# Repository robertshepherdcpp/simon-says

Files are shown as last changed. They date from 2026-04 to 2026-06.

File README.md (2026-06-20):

# simon-says
my fourth project for fallout

**what is this project**
- test out your memory with this memory game!
- this project tests your sequence memory, in having a sequence that increases in length after everytime you get it right
- see how far you can go! how many can you remember in a row

**assembly instructions**
- print out the pcb and the case, and purchase the components meantioned in the bom
- put the pcb in the case
- put on the lid. then attach the screws mentioned in the BOM to fix the pcb in place.
- flash the firmware to the xiao-esp32 through the arduino ide (via usb)
- keep it plugged into your computer, as that will be the power source!
- try and see how many you can remember!

**inspiration for the project**
- having played the sequence memory game on [human benchark](humanbenchmark.com), i wanted to have a physical version of this that i could play with!
- i thought it would be a good way to try and improve my memory as having it in physical form i think makes me more likely to use it.

**how it works**
- the project will show the seqence of keys 1 by 1, you simply copy these!
- see how many of these you can remember!
- if you have a high score, the project  will flash 3 times (this high score is stored on the permanent storage of esp-32 board. (using preferences.h)
- if you press the wrong key, then all leds will flash once, and the sequence will reset, (back to a seqeunce of length 1, then you have to memorize a new sequence)
- keep trying to beat the PB!

**how this project was made**
- case made using fusion360
- pcb made using kicad
- in the 3d model, the keycaps and cherry-switches were imported as step files from repos on github.

**screenshots**
the schematic:



the footprint:



pcb 3d:



the 3d model:



zine:



bom:



total project cost: $28.53 (however will already have components spare from other projects like cherry mx switches, key caps)

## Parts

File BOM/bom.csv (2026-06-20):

Name | Description | Price | Link | Running Total
XIAO-ESP32-C6 | the mcu | $9.34 | https://www.aliexpress.com/item/1005007427033011.html?af=137191_1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 | $9.34
Cherry MX switches | the keys | $5.09 | https://www.aliexpress.com/item/1005012067128405.html?af=137191_1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 | $14.43
Key caps | caps | $2.36 | https://www.aliexpress.com/item/1005005513800132.html?af=137191_1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 | $16.79
LEDs | smt 0603 | $1.69 | https://www.aliexpress.com/item/1005011897792884.html?af=137191_1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 | $18.48
Resistors | smt | $0.95 | https://www.aliexpress.com/item/1005008650089395.html?af=137191_1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 | $19.43
PCB | pcb fabrication | $4.00 | www.jlcpcb.com | $23.43
PCB shipping | shipping pcb | $3.30 | www.jlcpcb.com | $26.73
Case | - | N/A | N/A | N/A
MCP23017 | gpio expander | $1.80 | https://www.lcsc.com/product-detail/C506653.html | $28.53

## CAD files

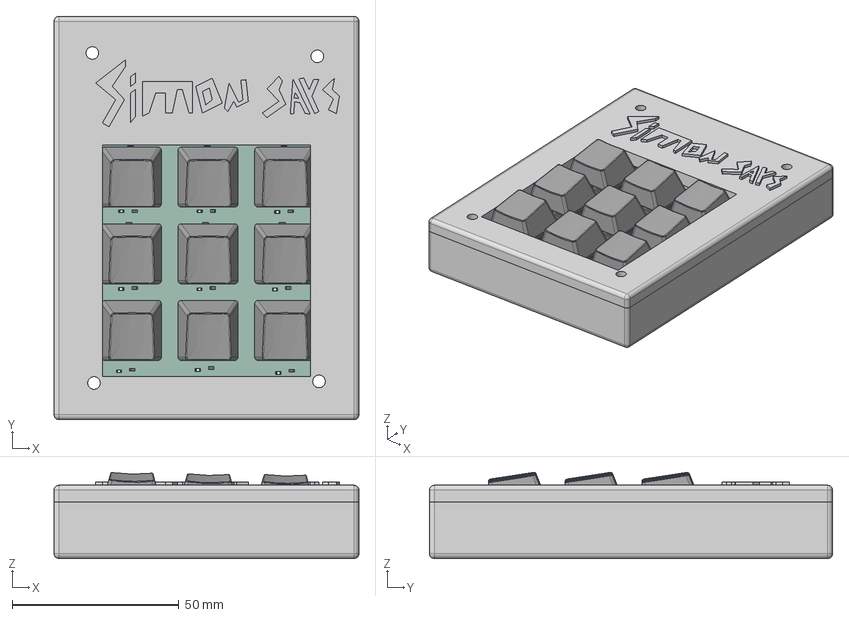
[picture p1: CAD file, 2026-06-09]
CAD/mg.step
91.5 x 121.0 x 25.8 mm
1x1 R1 v23 x 9
1x1 R2 v8 x 9
1x1 R3 v8 x 9
1x1 R4 v6 x 9
1x1.5 R1 v4 x 9
1x1.5 R3 v6 x 9
1x1.5 R4 v5 x 9
1x1.5 R2 v5 x 9
1x1.25 R1 v7 x 9
1x1.25 R2 v4 x 9
1x1.25 R4 v6 x 9
1x1.25 R3 v5 x 9
1x1.75 R1 v6 x 9
1x1.75 R2 v4 x 9
1x1.75 R4 v4 x 9
1x1.75 R3 v5 x 9
1x2 R1 v6 x 9
1x2 R4 v6 x 9
1x2 R3 v6 x 9
1x2 R2 v6 x 9
1x2.25 R1 v6 x 9
1x2.25 R2 v6 x 9
1x2.25 R4 v6 x 9
1x2.25 R3 v6 x 9
1x2.5 R1 v5 x 9
1x2.5 R2 v7 x 9
1x2.5 R3 v6 x 9
1x2.5 R4 v5 x 9
1x2.75 R1 v3 x 9
1x6.25 R1 v6 x 9
1x2.75 R4 v3 x 9
1x2.75 R3 v3 x 9
1x2.75 R2 v4 x 9
LED_0603_1608Metric x 9
R_0603_1608Metric x 9
QFN-28-1EP_6x6mm_P0.65mm_EP4.25x4.25mm
mg_PCB
BOSS-EXTRUDE14_8_
BOSS-EXTRUDE7_4_
BOSS-EXTRUDE7_3_
BOSS-EXTRUDE14_4_
BOSS-EXTRUDE14_2_
BOSS-EXTRUDE14_11_
BOSS-EXTRUDE7_7_
BOSS-EXTRUDE14_9_
BOSS-EXTRUDE14_3_
BOSS-EXTRUDE14_7_
MIRROR2
BOSS-EXTRUDE14_5_
BOSS-EXTRUDE14_12_
BOSS-EXTRUDE7_8_
BOSS-EXTRUDE7_1_
BOSS-EXTRUDE14_10_
BOSS-EXTRUDE7_9_
BOSS-EXTRUDE14_6_
BOSS-EXTRUDE14_1_
BOSS-EXTRUDE7_6_
BOSS-EXTRUDE7_2_
CUT-EXTRUDE5
BOSS-EXTRUDE7_5_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

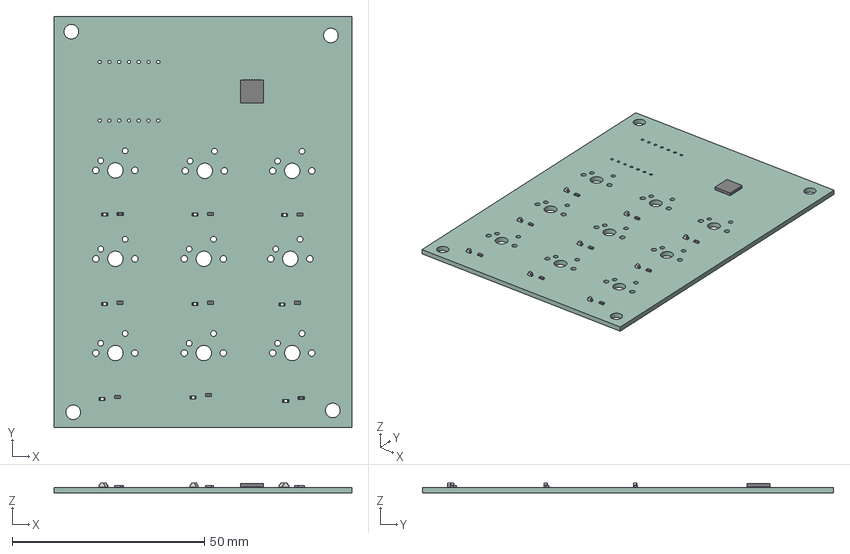
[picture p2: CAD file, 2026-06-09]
PCB/mg.step
77.5 x 107.0 x 2.70 mm
LED_0603_1608Metric x 9
R_0603_1608Metric x 9
QFN-28-1EP_6x6mm_P0.65mm_EP4.25x4.25mm
mg_PCB

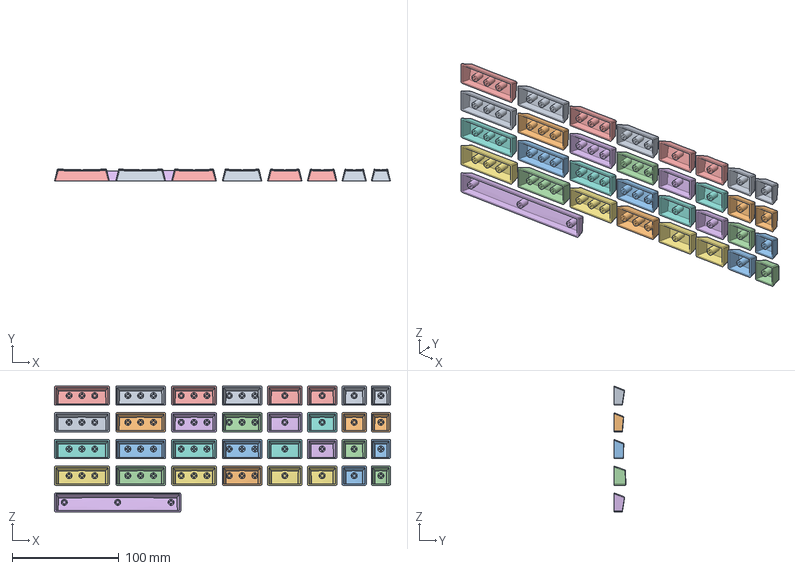
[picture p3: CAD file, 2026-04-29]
CAD/Cherry MX keycaps.step
314.7 x 11.2 x 118.0 mm
1x1 R1 v23
1x1 R2 v8
1x1 R3 v8
1x1 R4 v6
1x1.5 R1 v4
1x1.5 R3 v6
1x1.5 R4 v5
1x1.5 R2 v5
1x1.25 R1 v7
1x1.25 R2 v4
1x1.25 R4 v6
1x1.25 R3 v5
1x1.75 R1 v6
1x1.75 R2 v4
1x1.75 R4 v4
1x1.75 R3 v5
1x2 R1 v6
1x2 R4 v6
1x2 R3 v6
1x2 R2 v6
1x2.25 R1 v6
1x2.25 R2 v6
1x2.25 R4 v6
1x2.25 R3 v6
1x2.5 R1 v5
1x2.5 R2 v7
1x2.5 R3 v6
1x2.5 R4 v5
1x2.75 R1 v3
1x6.25 R1 v6
1x2.75 R4 v3
1x2.75 R3 v3
1x2.75 R2 v4

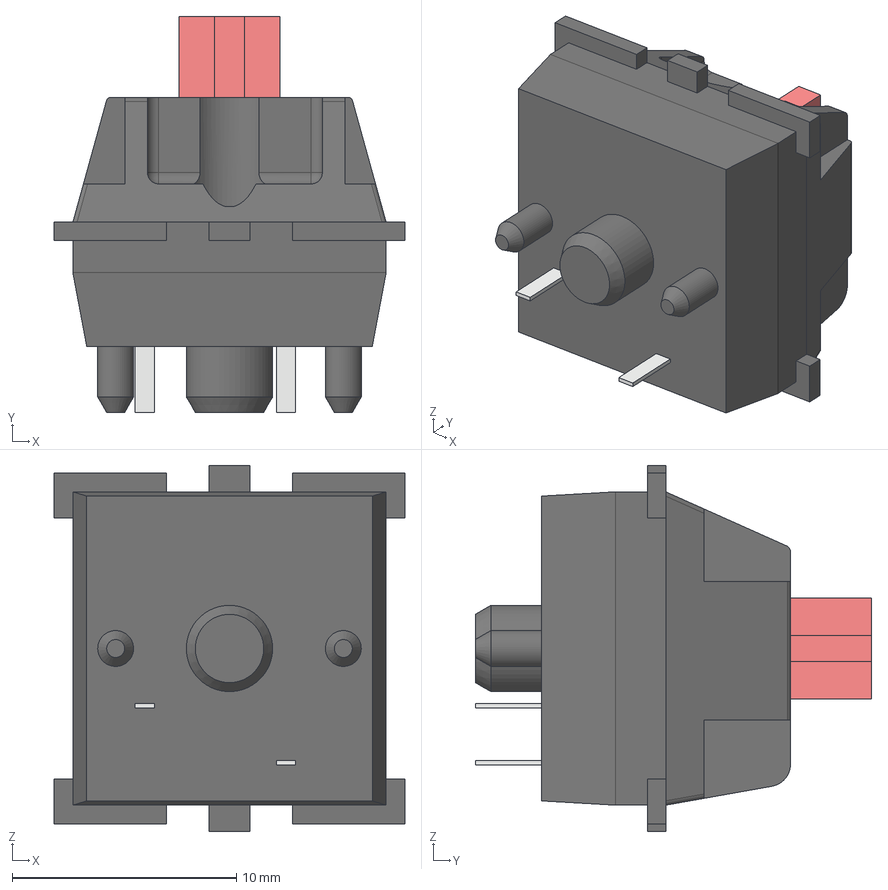
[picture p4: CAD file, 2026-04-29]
CAD/switch.step
15.6 x 17.7 x 16.3 mm

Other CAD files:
CAD/mg.f3z

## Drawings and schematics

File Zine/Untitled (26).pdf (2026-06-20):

# simon says the memory game

## keys, leds!

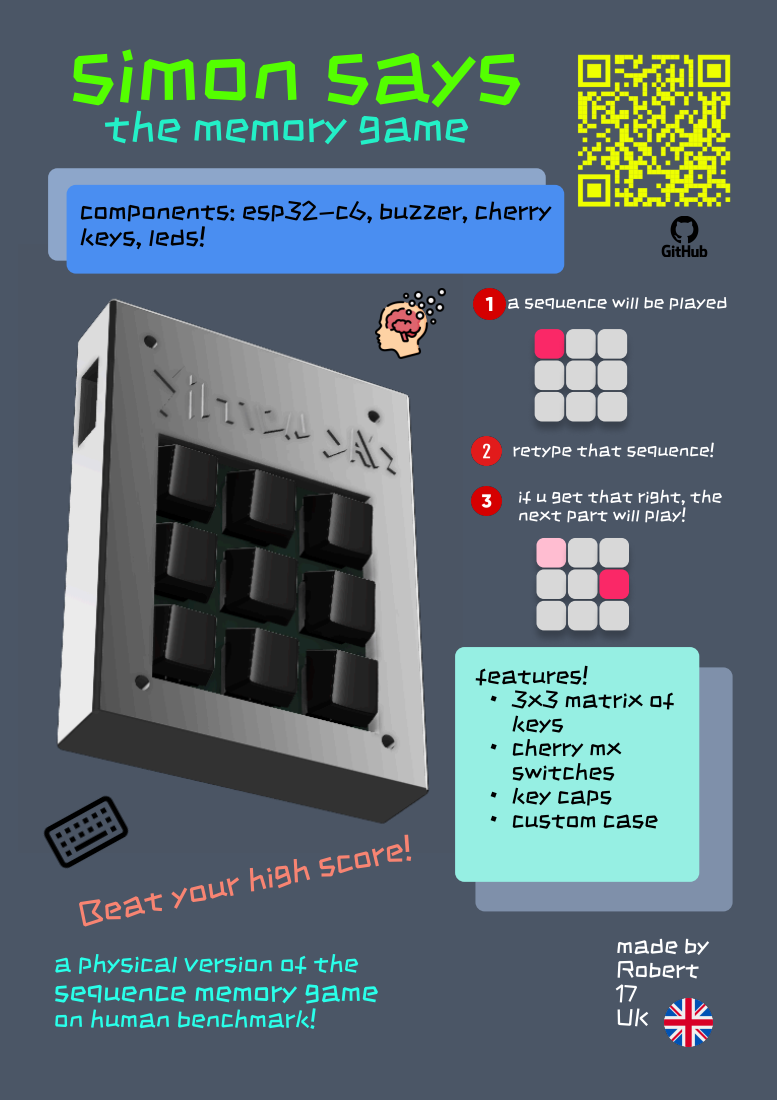
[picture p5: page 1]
features! 3x3 matrix of; keys; cherry mx; switches key caps; custom case; made by Robert 17 UK

components: esp32-c6, buzzer, cherry

a sequence will be played

retype that sequence!

if u get that right, the next part will play!

Beat your high score!

a physical version of the sequence memory game

on human benchmark!

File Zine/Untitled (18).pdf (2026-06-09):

# simon says

# the memory game

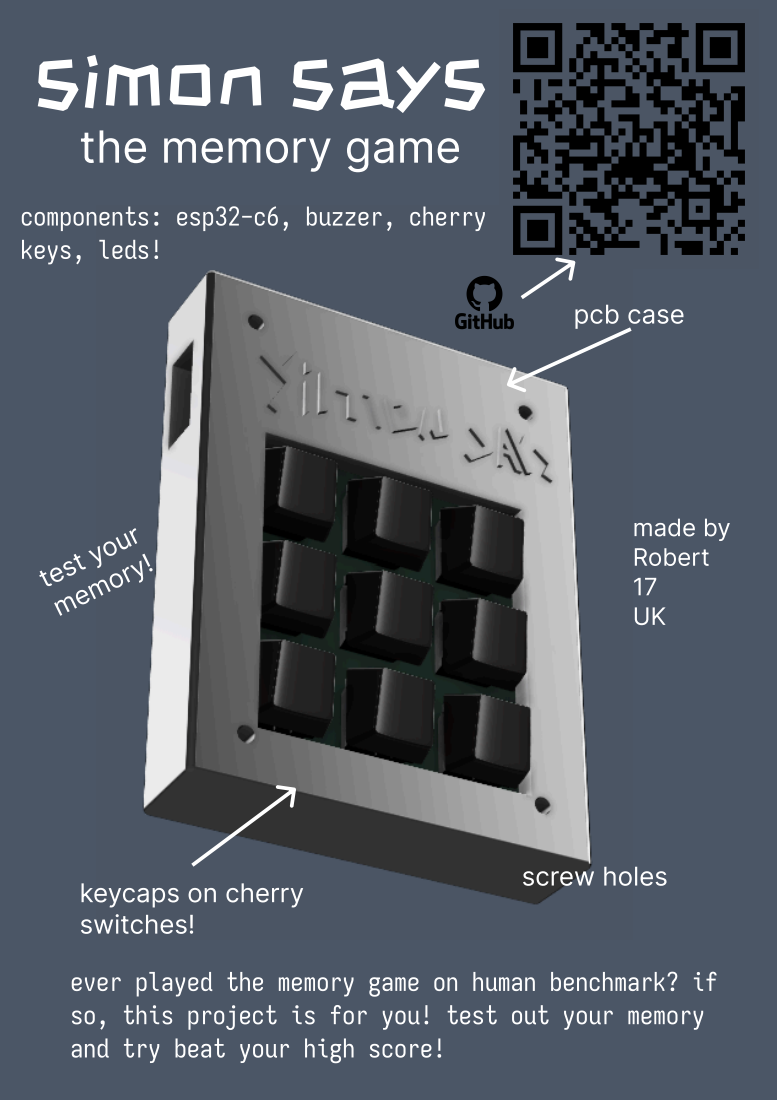
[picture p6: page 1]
keys, leds!; pcb case; test your memory!; made by; Robert; switches!

components: esp32-c6, buzzer, cherry

screw holes keycaps on cherry

ever played the memory game on human benchmark? if
so, this project is for you! test out your memory

and try beat your high score!

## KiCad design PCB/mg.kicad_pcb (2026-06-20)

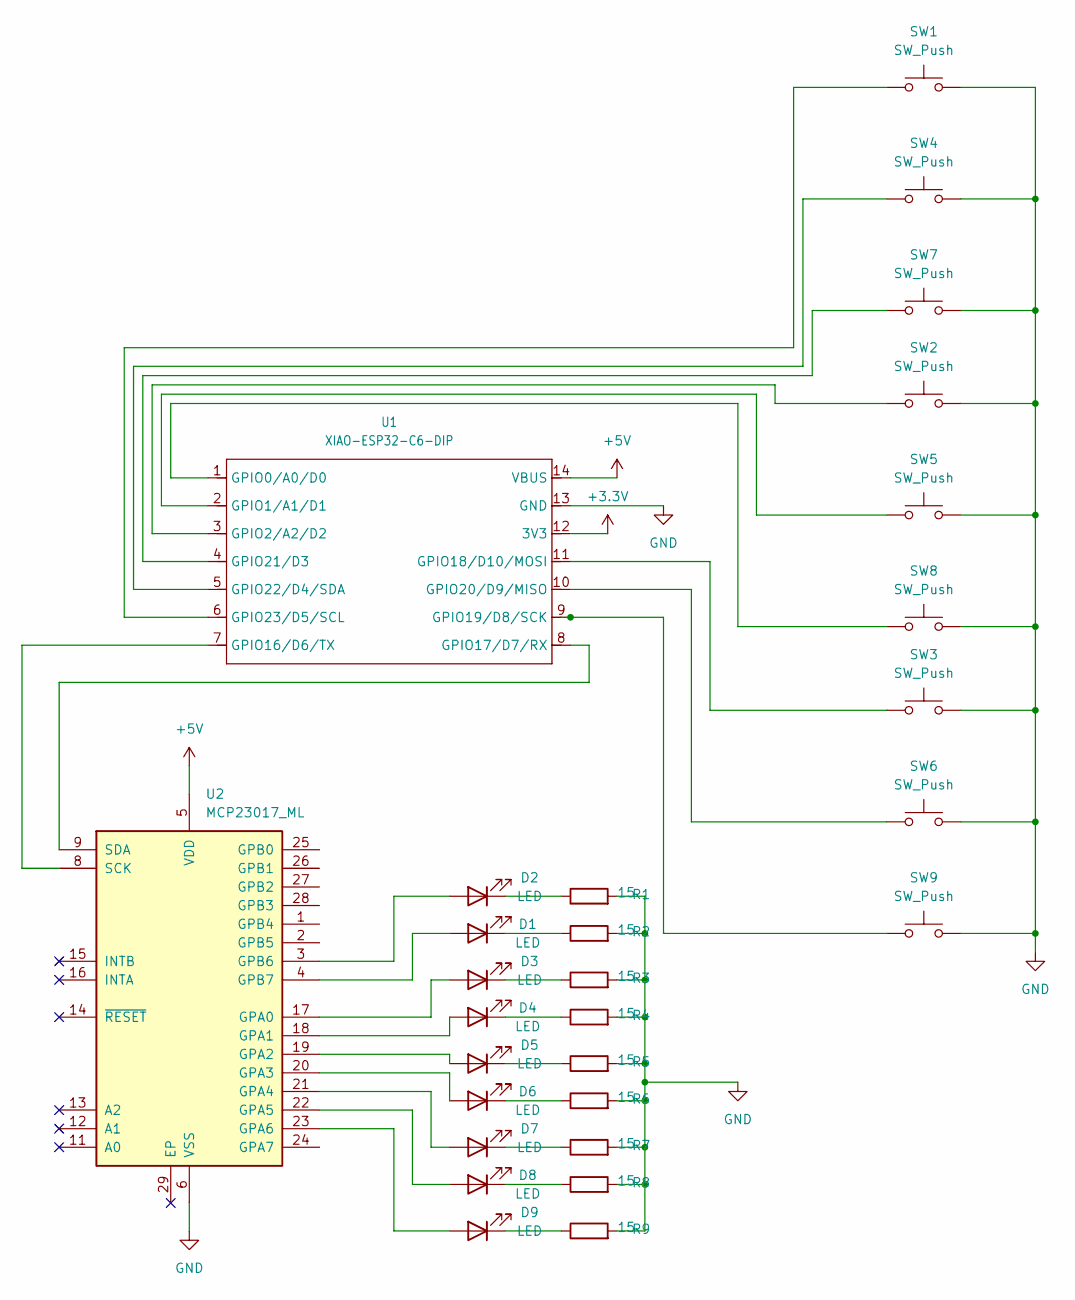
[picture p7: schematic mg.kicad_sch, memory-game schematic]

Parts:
D1, D2, D3, D4, D5, D6, D7, D8, D9: LED; LED_0603_1608Metric
R1, R2, R3, R4, R5, R6, R7, R8, R9: 15; R_0603_1608Metric
SW1, SW2, SW3, SW4, SW5, SW6, SW7, SW8, SW9: SW_Push; SW_Cherry_MX_1.00u_PCB
U1: XIAO-ESP32-C6-DIP
U2: MCP23017_ML; QFN-28-1EP_6x6mm_P0.65mm_EP4.25x4.25mm

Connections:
+3.3V: U1.12 (3V3)
+5V: U1.14 (VBUS), U2.5 (VDD)
GND: R1.2, R2.2, R3.2, R4.2, R5.2, R6.2, R7.2, R8.2, R9.2, SW1.2, SW2.2, SW3.2, SW4.2, SW5.2, SW6.2, SW7.2, SW8.2, SW9.2, U1.13 (GND), U2.6 (VSS)
unnamed: D1.2 (A), U2.4 (GPB7)
unnamed: D1.1 (K), R2.1
unnamed: D2.2 (A), U2.3 (GPB6)
unnamed: D2.1 (K), R1.1
unnamed: D3.2 (A), U2.17 (GPA0)
unnamed: D3.1 (K), R3.1
unnamed: D4.2 (A), U2.18 (GPA1)
unnamed: D4.1 (K), R4.1
unnamed: D5.2 (A), U2.19 (GPA2)
unnamed: D5.1 (K), R5.1
unnamed: D6.2 (A), U2.20 (GPA3)
unnamed: D6.1 (K), R6.1
unnamed: D7.2 (A), U2.21 (GPA4)
unnamed: D7.1 (K), R7.1
unnamed: D8.2 (A), U2.22 (GPA5)
unnamed: D8.1 (K), R8.1
unnamed: D9.2 (A), U2.23 (GPA6)
unnamed: D9.1 (K), R9.1
unnamed: SW8.1, U1.1 (GPIO0/A0/D0)
unnamed: SW5.1, U1.2 (GPIO1/A1/D1)
unnamed: SW2.1, U1.3 (GPIO2/A2/D2)
unnamed: U1.7 (GPIO16/D6/TX), U2.8 (SCK)
unnamed: U1.8 (GPIO17/D7/RX), U2.9 (SDA)
unnamed: SW3.1, U1.11 (GPIO18/D10/MOSI)
unnamed: SW9.1, U1.9 (GPIO19/D8/SCK)
unnamed: SW6.1, U1.10 (GPIO20/D9/MISO)
unnamed: SW7.1, U1.4 (GPIO21/D3)
unnamed: SW4.1, U1.5 (GPIO22/D4/SDA)
unnamed: SW1.1, U1.6 (GPIO23/D5/SCL)

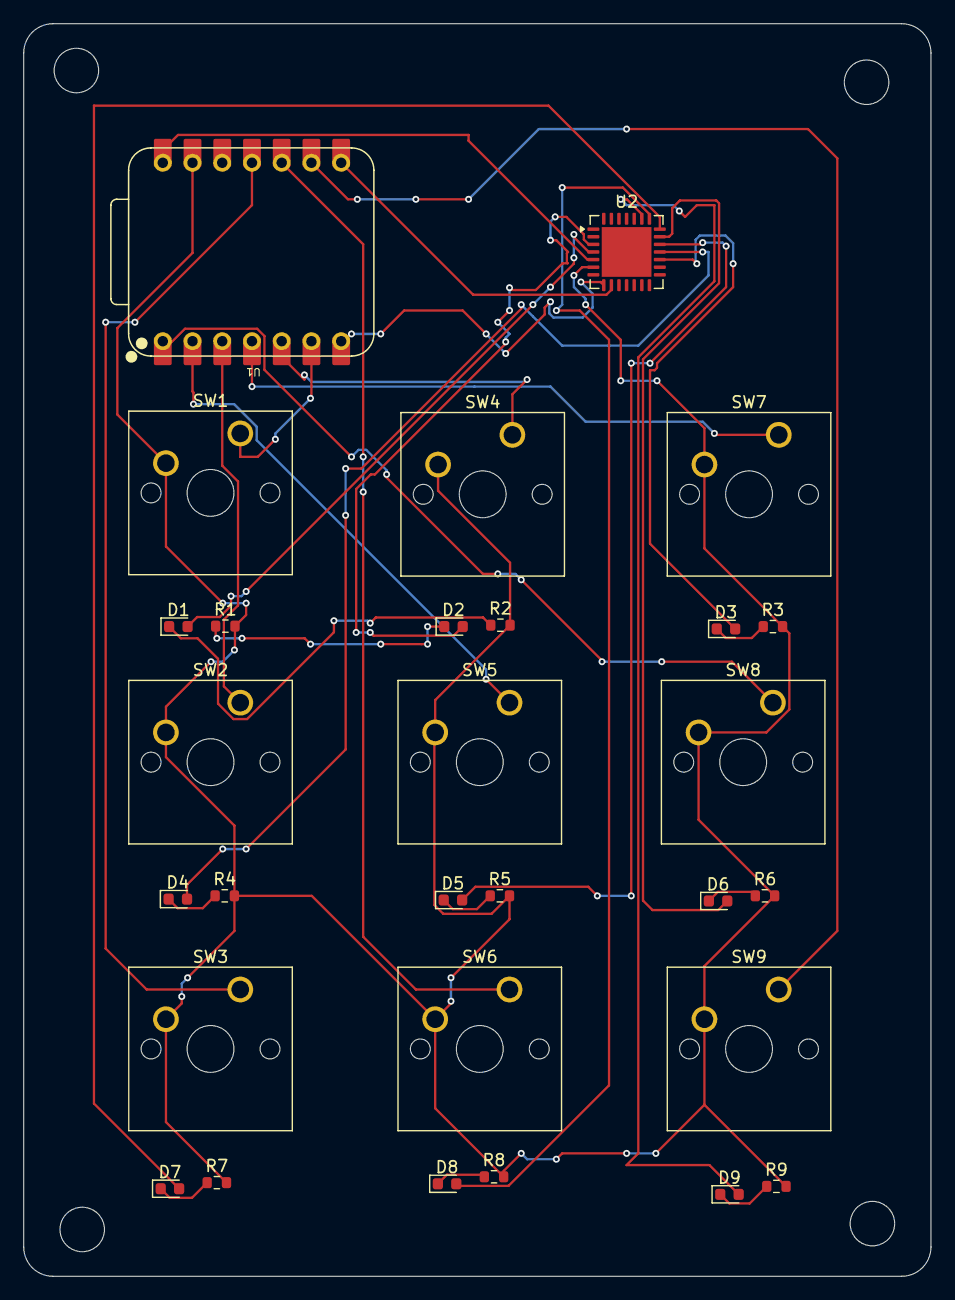
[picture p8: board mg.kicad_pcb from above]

Board: 2 copper layers, 77.5 x 107.0 mm, 29 parts (0 on the bottom side), 31 nets.

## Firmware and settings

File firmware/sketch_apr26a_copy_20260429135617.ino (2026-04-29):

#include "Adafruit_MCP23X17.h"
#include <Adafruit_GFX.h>
#include <Adafruit_SSD1306.h>
#include <Vector.h>
#include <Preferences.h>

// the MCP23017
#define LED1 6
#define LED2 7
#define LED3 21
#define LED4 22
#define LED5 23
#define LED6 24
#define LED7 25
#define LED8 26
#define LED9 27

// esp
#define MCP23017SCK 19
#define MCP23017SDA 20

#define Btn1 11
#define Btn2 10
#define Btn3 9
#define Btn4 0
#define Btn5 1
#define Btn6 2
#define Btn7 21
#define Btn8 22
#define Btn9 23

Adafruit_MCP23X17 mcp;

Preferences pr;

void setup() {
  // leds
  mcp.pinMode(LED1, OUTPUT);
  mcp.pinMode(LED2, OUTPUT);
  mcp.pinMode(LED3, OUTPUT);
  mcp.pinMode(LED4, OUTPUT);

  // buttons
  pinMode(Btn1, INPUT_PULLUP);
  pinMode(Btn2, INPUT_PULLUP);
  pinMode(Btn3, INPUT_PULLUP);
  pinMode(Btn4, INPUT_PULLUP);
  pinMode(Btn5, INPUT_PULLUP);
  pinMode(Btn6, INPUT_PULLUP);
  pinMode(Btn7, INPUT_PULLUP);
  pinMode(Btn8, INPUT_PULLUP);
  pinMode(Btn9, INPUT_PULLUP);
}

// we have a maximum of 128 elements
constexpr size_t ELEMENT_COUNT_MAX = 128;
int storage[ELEMENT_COUNT_MAX];
Vector<int> v(storage);
int current_index = 0; // current index of where the user is at.
int score = 0; // how many successive presses they got right.

auto get_random_number() {
  return random(1, 10);
}

int leds[9] = {LED1, LED2, LED3, LED4, LED5, LED6, LED7, LED8, LED9};

auto play_sequence() {
  for(int i = 0; i < v.size(); i++) {
    int num = v[i] - 1;
    mcp.digitalWrite(leds[num], HIGH);
    delay(1000);
    mcp.digitalWrite(leds[num], LOW);
  }
}

auto showError() {
  // blink all leds.
  for(int i = 0; i < 9; i++) {
    mcp.digitalWrite(leds[i], HIGH);
  }
  delay(1000);
  for(int i = 0; i < 9; i++) {
    mcp.digitalWrite(leds[i], LOW);
  }
}

auto showWin() {
  // blink 3 times.
  for(int i = 0; i < 9; i++) {
    mcp.digitalWrite(leds[i], HIGH);
  }
  delay(1000);
  for(int i = 0; i < 9; i++) {
    mcp.digitalWrite(leds[i], LOW);
  }
  delay(1000);
  for(int i = 0; i < 9; i++) {
    mcp.digitalWrite(leds[i], HIGH);
  }
  delay(1000);
  for(int i = 0; i < 9; i++) {
    mcp.digitalWrite(leds[i], LOW);
  }
  delay(1000);
  for(int i = 0; i < 9; i++) {
    mcp.digitalWrite(leds[i], HIGH);
  }
  delay(1000);
  for(int i = 0; i < 9; i++) {
    mcp.digitalWrite(leds[i], LOW);
  }
}

void loop() {
  bool flag = false;
  if(v.size() == 0) {
    v.push_back(get_random_number());
    play_sequence();
  } else {
    // checking which button was pressed
    int btns[9] = {Btn1, Btn2, Btn3, Btn4, Btn5, Btn6, Btn7, Btn8, Btn9};
    for(int i = 0; i < 9; i++) {
      if(digitalRead(btns[i]) == HIGH) {
        if(v[current_index] == i+1) {
          flag = true;
          score += 1;
        } else {
          showError();

          pr.begin("my-app", false);
          int high_score = pr.getInt("highScore", 0);
          if(score > high_score) {
            pr.putInt("highScore", score);
            showWin();
          }
          pr.end();

          score = 0;
          v.clear();
          current_index = 0;
        }
      }
      delay(250); // wait so we dont get duplicate presses counted.
      break;
    }

    if(flag) {
      // then check if we have reached the end of the sequence, if so, we just play the sequence
      if(v.size()-1 == current_index) {
        v.push_back(get_random_number());
        play_sequence();
      }
      else {
        current_index += 1;
      }
    }

    // if(digitalRead(Btn1) == HIGH) {
    //   if(v[current_index] == 1) {
    //     flag = true;
    //     score += 1;
    //   } else {
    //     // the user got it wrong, so we reset
    //     showError(); // should flash all LEDs
    //   }
    // }
  }
}

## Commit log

2026-04-29 add the pcb files
    [mg.kicad_pcb, mg.kicad_sch, mg.step]
2026-04-29 Rename Cherry MX keycaps.step to CAD/Cherry MX keycaps.step
    [Cherry MX keycaps.step]
2026-04-29 Fix formatting issue in BOM CSV for MCP23017
    [bom.csv]
2026-04-29 Add BOM image and project cost information
    Added an image for the BOM section and provided cost details.
2026-06-04 add the actual mcp23017 chip
    [bom.csv]
2026-06-04 add the updataed cherry mx keycaps step file
    [Cherry MX keycaps.step]
2026-06-09 Add total cost row to BOM CSV
    [bom.csv]
2026-06-09 uploading the new pcb files (with the cutout in the pcb)
    [mg.kicad_pcb, mg.kicad_sch, mg.step]
2026-06-09 add the updated gerber files.
2026-06-09 add the cad files.
    [mg.f3z, mg.step]
2026-06-15 Revise assembly instructions in README
    Updated assembly instructions for clarity and detail.
2026-06-20 Change product links to AliExpress
    Updated product links to point to AliExpress for better availability.
    [bom.csv]
2026-06-20 add updated schematic.
    [mg.kicad_sch]
2026-06-20 add updated schematic image to the readme.
2026-06-20 add updated pcb files.
    [mg.kicad_pcb, mg.kicad_sch, mg.step]
